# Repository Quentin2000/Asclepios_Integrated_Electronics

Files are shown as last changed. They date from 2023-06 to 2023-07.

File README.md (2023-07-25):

# Master Project

## Integration of a miniaturized O2 sensor into a space suit helmet.

#### Author: Quentin Delfosse
#### Academic Supervisor: Pr. Guillermo Villanueva
#### Technical Supervisor: Arnault Monoyer

## Repository files

This repository includes the following design files:
- **HW**: Kicad hardware files for the interface board and air quality sensor board.
- **SW**: Arduino files used to flash the ESP32 S2 Mini 1 computer.
- **SD**: Setup files for the SD card.

To access CAD design files, please refer to the Google Drive: https://drive.google.com/drive/folders/1vZVMf6BT2zpStATiHxgfttCtssU6DIhK?usp=drive_link.

## Introduction

Asclepios is a student-led project from Switzerland aiming at organizing simulations of manned space missions. For this purpose, the association rents existing infrastructure and builds its base inside. Therefore, by design, the mission will take place on Earth, where many parameters are different than on other celestial bodies. However, the analog astronauts will live together in close contact during the two weeks of the mission to experience the constraints of extraterrestrial environments during the Earth-based simulation. The project aims at optimizing their environment to make their mission as realistic as possible.

<br />

This project aims at integrating a miniaturized O2 sensor into a space suit helmet to monitor the user's breathable atmosphere. Both mechanical and electrical sensor integration will be required. Additionally, the sensor data will need to be processed. Thus, a graphical interface for the visualization of the O2 data in real time will need to be created.

<p align="center">
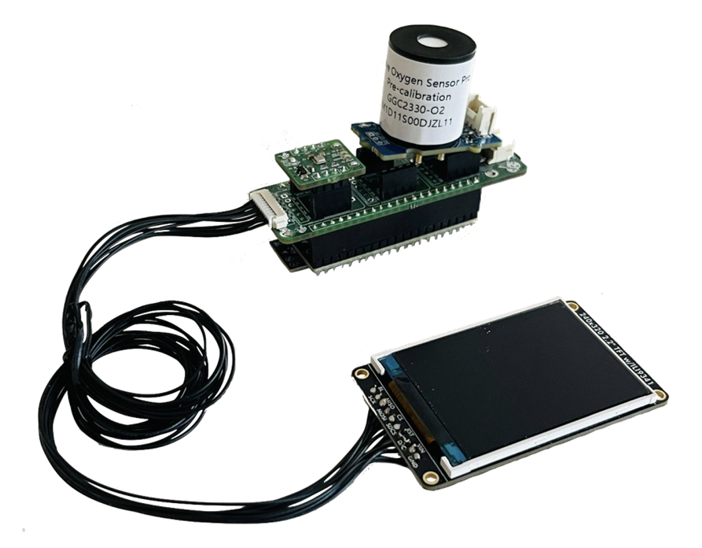
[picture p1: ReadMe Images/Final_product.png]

</p>

## Setup

### Hardware

The system is made of 3 stacked layers:
- **Upper stage**: Sensor stage (O2 + Air quality sensors)
- **Middle stage**: Interface stage 
- **Lower stage**: Main computer stage (ESP32 S2 Mini 1)

**CAREFUL: Before connecting two boards together, please make sure that the signals on both end match! This can be checked on the surface of the boards! Otherwise you may fry the sensors and the computer!**

To assemble the system, simply stack the layers on top of each other:
- Connect the main computer board (black one) to the interface board (long green one).
- **Make sure to check that the signals match: 3V3, Ground, 5V!**
- Insert the SD card into the interface board (bottom face).
- Connect the screen to the interface board (long white connector).
- Connect the Air quality sensor board (small green one) on top of the rooting board (long green one).
- **Again, check that the signals match: 3V3, Ground, 5V!**
- Place the stacked-up module on the 4 rails of the bottom cover. Only one orientation should fit.
- Connect the O2 sensor cable to the O2 sensor board.
- Insert the O2 sensor into the top cover hole, following the 2 rails and making sure that its cable comes out through the dedicated hole on the side.
- Place a foam on top of the interface board where the O2 sensor will be positioned (next to the air quality sensor).
- Close both end on the case together.
- Plug a USB cable to the micro usb port of the main computer and connect it to the portable battery.
- Power up the battery.

The screen should initialize after a couple of seconds and show a similar screen as the following one:
<p align="center">
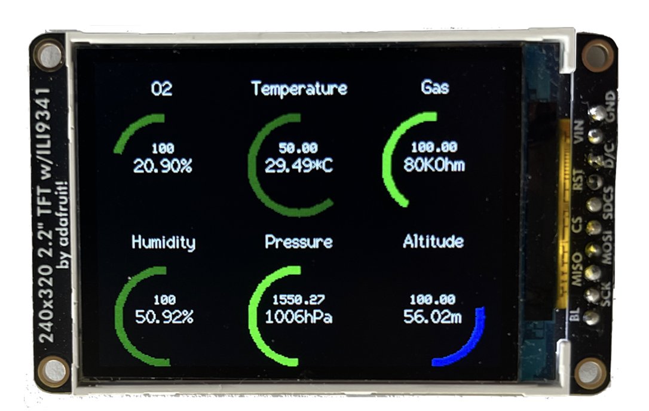
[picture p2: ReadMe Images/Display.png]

</p>

The following figure shows a guidethrough of the procedure.
<p align="center">
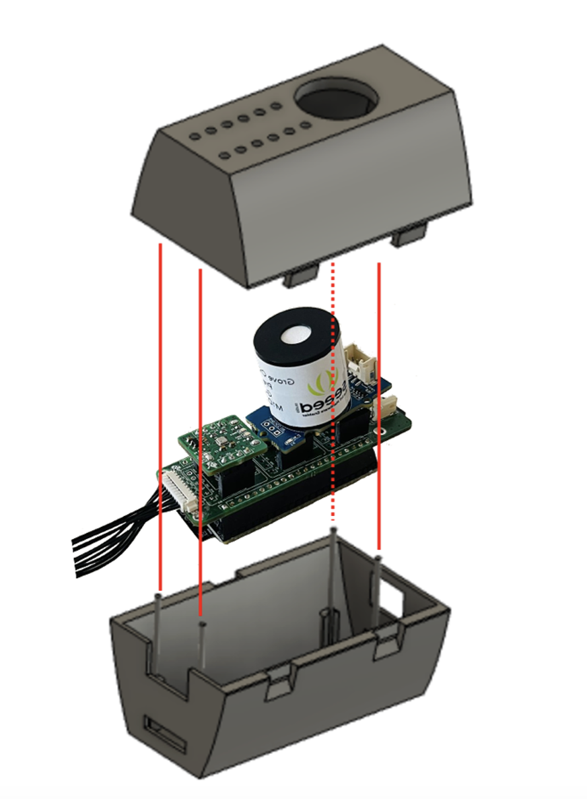
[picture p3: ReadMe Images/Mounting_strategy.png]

</p>

### Software

To display the sensors data, you will need the following package:
```ruby
pip install pandas 
```

To retrieve the data from the SD card, the following procedure must be applied:
- Plug it into your computer
- Open the SD card folder and check the mission log which you want to display
- Open a terminal window
- Go to the SD card directory, something like the following for MAC OS users.
```ruby
 cd /Volumes/NO\ NAME 
```
- Type the following command, where **x** is the number of the mission log to display. You may also need to change to **python** instead of **python3** depending on your computer
```ruby
python3 display.py mission_log_x 
```

This will create a png file with the sensor graphs over the mission duration and an excel file with these values.
<p align="center">
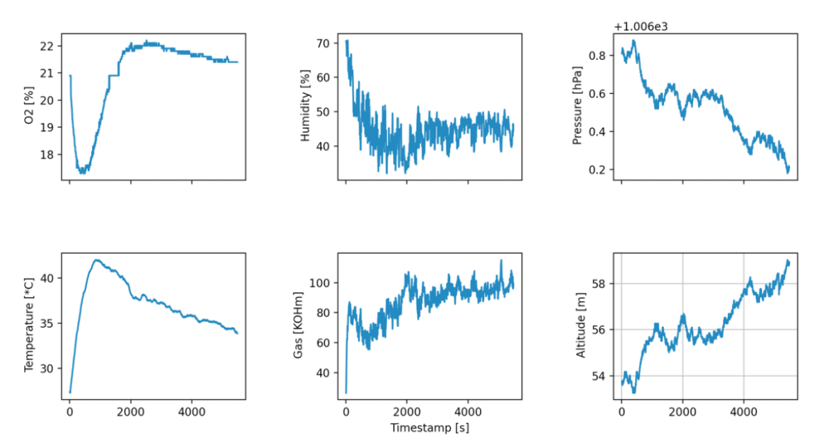
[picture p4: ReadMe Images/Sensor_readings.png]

</p>

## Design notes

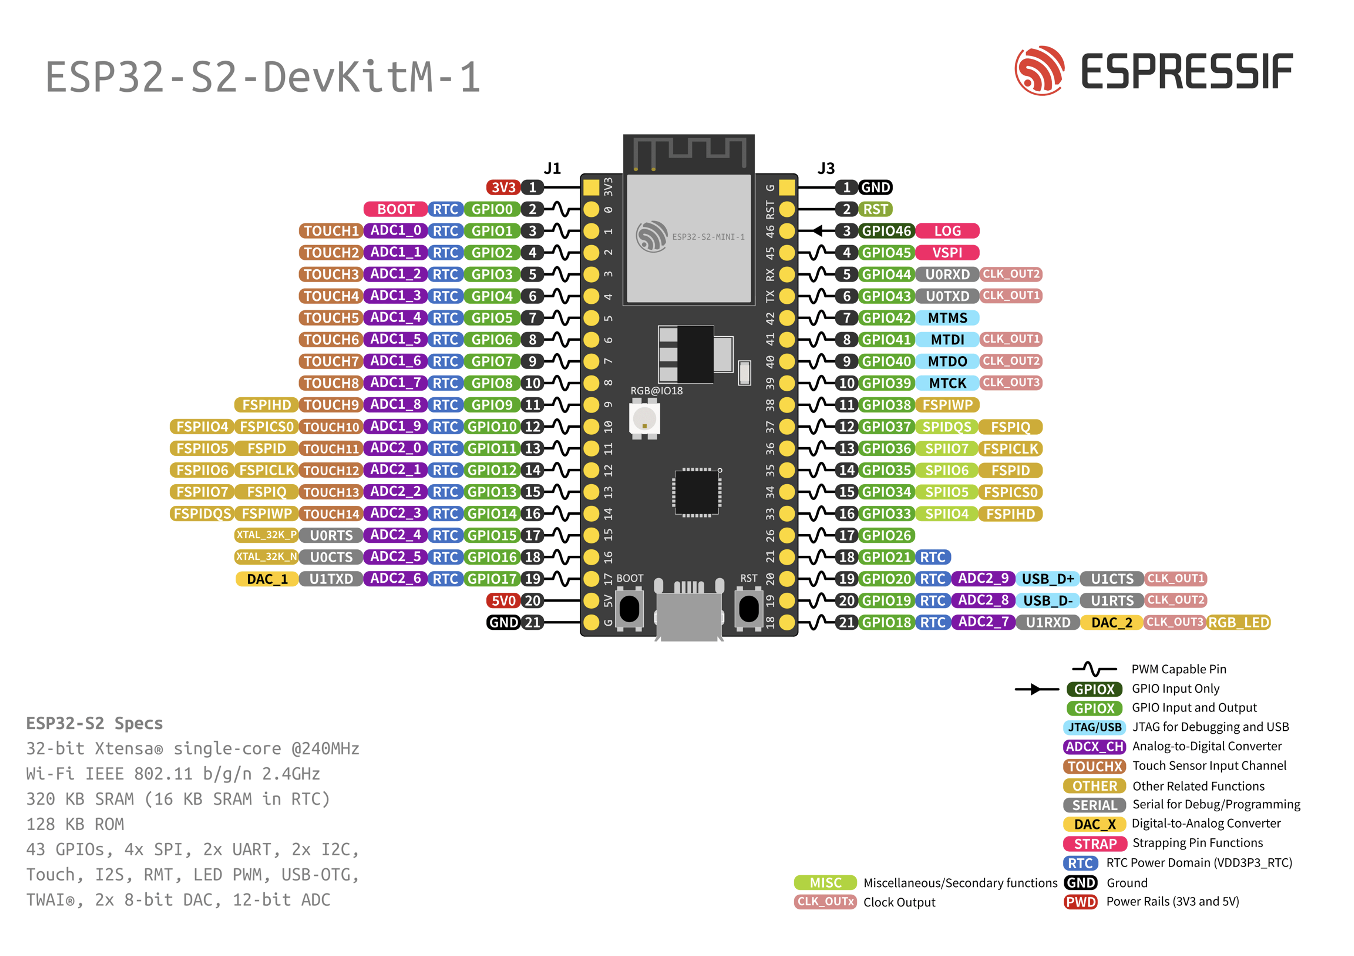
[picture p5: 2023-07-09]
ReadMe Images/Espressif_pinout.png

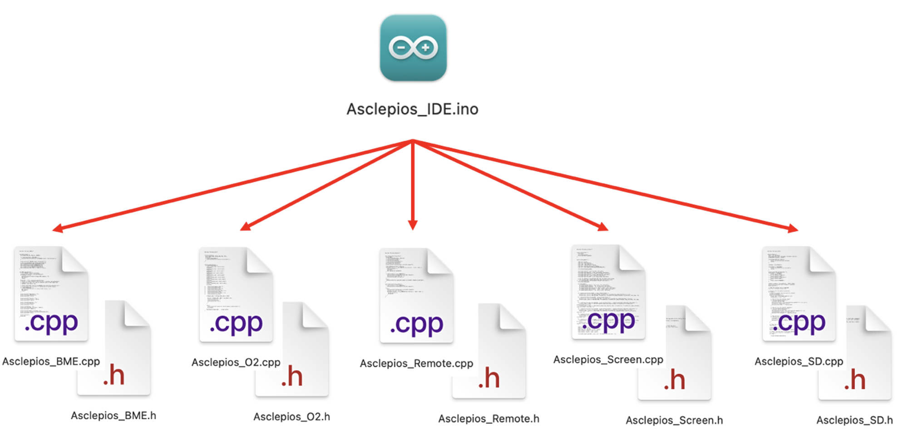
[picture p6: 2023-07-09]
ReadMe Images/SW_Architecture.png

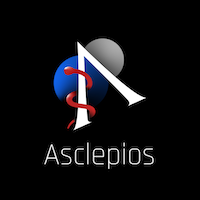
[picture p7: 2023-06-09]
SW/asclepios.bmp

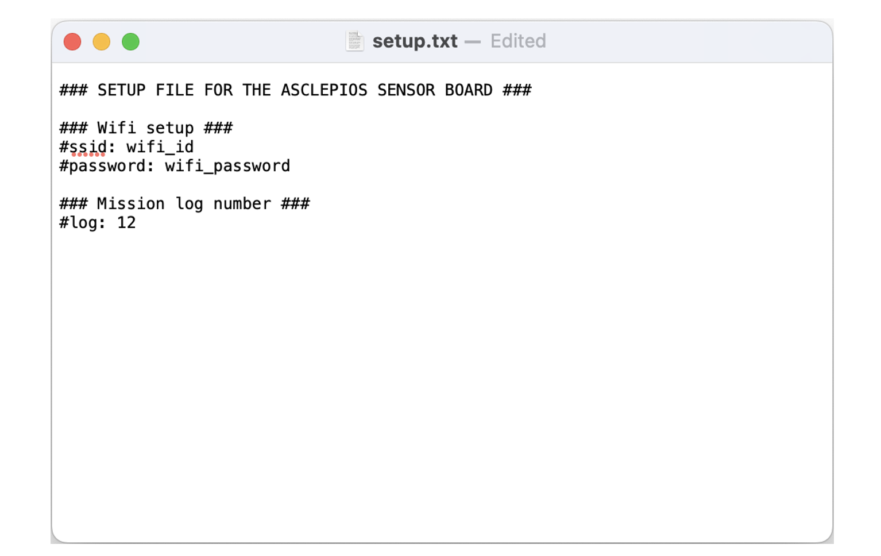
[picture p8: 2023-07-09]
ReadMe Images/SD_config_file.png

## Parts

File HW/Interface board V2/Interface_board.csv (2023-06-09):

Source: | /Users/quentin/Documents/Asclepios/HW/Interface board/Interface_board.kicad_sch
Date: | Wednesday, March 08, 2023 at 01:37:11 PM
Tool: | Eeschema (6.0.8-1)-1
Generator: | /Applications/KiCad/KiCad.app/Contents/SharedSupport/plugins/bom_csv_grouped_by_value.py
Component Count: | 25
Individual Components:
Item | Qty | Reference(s) | Value | LibPart | Footprint | Datasheet | MANUFACTURER | PARTREV | STANDARD
 |  | H0 | MountingHole | Mechanical:MountingHole | MountingHole:MountingHole_2.2mm_M2_DIN965_Pad_TopBottom | ~
 |  | H1 | MountingHole | Mechanical:MountingHole | MountingHole:MountingHole_2.2mm_M2_DIN965_Pad_TopBottom | ~
 |  | H2 | MountingHole | Mechanical:MountingHole | MountingHole:MountingHole_2.2mm_M2_DIN965_Pad_TopBottom | ~
 |  | H3 | MountingHole | Mechanical:MountingHole | MountingHole:MountingHole_2.2mm_M2_DIN965_Pad_TopBottom | ~
 |  | H4 | MountingHole | Mechanical:MountingHole | MountingHole:MountingHole_2.2mm_M2_DIN965_Pad_TopBottom | ~
 |  | J1 | ESP32_Conn_J1 | Connector:Conn_01x21_Female | Connector_PinHeader_2.54mm:PinHeader_1x21_P2.54mm_Vertical | ~
 |  | J2 | Mico_SD_Socket | 503398-1892:503398-1892 | MOLEX_503398-1892 |  | molex | 0 | MANUFACTURER RECOMMENDATIONS
 |  | J3 | ESP32_Conn_J3 | Connector:Conn_01x21_Female | Connector_PinHeader_2.54mm:PinHeader_1x21_P2.54mm_Vertical | ~
 |  | J10 | Conn_01x06_Female | Connector:Conn_01x06_Female | Connector_PinSocket_2.54mm:PinSocket_1x06_P2.54mm_Vertical | ~
 |  | J11 | Conn_01x04_Female | Connector:Conn_01x04_Female | Connector_PinSocket_2.54mm:PinSocket_1x04_P2.54mm_Vertical | ~
 |  | J12 | Conn_01x04_Female | Connector:Conn_01x04_Female | Connector_PinSocket_2.54mm:PinSocket_1x04_P2.54mm_Vertical | ~
 |  | J13 | Conn_01x04_Female | Connector:Conn_01x04_Female | Connector_PinSocket_2.54mm:PinSocket_1x04_P2.54mm_Vertical | ~
 |  | J20 | Conn_01x06_Female | Connector:Conn_01x06_Female | Connector_PinSocket_2.54mm:PinSocket_1x06_P2.54mm_Vertical | ~
 |  | J21 | Conn_01x04_Female | Connector:Conn_01x04_Female | Connector_PinSocket_2.54mm:PinSocket_1x04_P2.54mm_Vertical | ~
 |  | J22 | Conn_01x04_Female | Connector:Conn_01x04_Female | Connector_PinSocket_2.54mm:PinSocket_1x04_P2.54mm_Vertical | ~
 |  | J23 | Conn_01x04_Female | Connector:Conn_01x04_Female | Connector_PinSocket_2.54mm:PinSocket_1x04_P2.54mm_Vertical | ~
 |  | J30 | Conn_01x06_Female | Connector:Conn_01x06_Female | Connector_PinSocket_2.54mm:PinSocket_1x06_P2.54mm_Vertical | ~
 |  | J31 | Conn_01x04_Female | Connector:Conn_01x04_Female | Connector_PinSocket_2.54mm:PinSocket_1x04_P2.54mm_Vertical | ~
 |  | J32 | Conn_01x04_Female | Connector:Conn_01x04_Female | Connector_PinSocket_2.54mm:PinSocket_1x04_P2.54mm_Vertical_SMD_Pin1Left | ~
 |  | J33 | Conn_01x04_Female | Connector:Conn_01x04_Female | Connector_PinSocket_2.54mm:PinSocket_1x04_P2.54mm_Vertical | ~
 |  | J40 | Screen_connector | Connector:Conn_01x10_Female | Connector_Molex:Molex_PicoBlade_53048-1010_1x10_P1.25mm_Horizontal | ~
 |  | JP1 | SolderJumper_3_Open | Jumper:SolderJumper_3_Open | Jumper:SolderJumper-3_P1.3mm_Open_RoundedPad1.0x1.5mm | ~
 |  | JP2 | SolderJumper_3_Open | Jumper:SolderJumper_3_Open | Jumper:SolderJumper-3_P1.3mm_Open_RoundedPad1.0x1.5mm | ~
 |  | JP3 | SolderJumper_3_Open | Jumper:SolderJumper_3_Open | Jumper:SolderJumper-3_P1.3mm_Open_RoundedPad1.0x1.5mm | ~
 |  | JP4 | SolderJumper_3_Open | Jumper:SolderJumper_3_Open | Jumper:SolderJumper-3_P1.3mm_Open_RoundedPad1.0x1.5mm | ~
Collated Components:
Item | Qty | Reference(s) | Value | LibPart | Footprint | Datasheet | MANUFACTURER | PARTREV | STANDARD
1 | 5 | H0, H1, H2, H3, H4 | MountingHole | Mechanical:MountingHole | MountingHole:MountingHole_2.2mm_M2_DIN965_Pad_TopBottom | ~
2 | 1 | J1 | ESP32_Conn_J1 | Connector:Conn_01x21_Female | Connector_PinHeader_2.54mm:PinHeader_1x21_P2.54mm_Vertical | ~
3 | 1 | J2 | Mico_SD_Socket | 503398-1892:503398-1892 | MOLEX_503398-1892 |  | molex | 0 | MANUFACTURER RECOMMENDATIONS
4 | 1 | J3 | ESP32_Conn_J3 | Connector:Conn_01x21_Female | Connector_PinHeader_2.54mm:PinHeader_1x21_P2.54mm_Vertical | ~
5 | 3 | J10, J20, J30 | Conn_01x06_Female | Connector:Conn_01x06_Female | Connector_PinSocket_2.54mm:PinSocket_1x06_P2.54mm_Vertical | ~
6 | 8 | J11, J12, J13, J21, J22, J23, J31, J33 | Conn_01x04_Female | Connector:Conn_01x04_Female | Connector_PinSocket_2.54mm:PinSocket_1x04_P2.54mm_Vertical | ~
7 | 1 | J32 | Conn_01x04_Female | Connector:Conn_01x04_Female | Connector_PinSocket_2.54mm:PinSocket_1x04_P2.54mm_Vertical_SMD_Pin1Left | ~
8 | 1 | J40 | Screen_connector | Connector:Conn_01x10_Female | Connector_Molex:Molex_PicoBlade_53048-1010_1x10_P1.25mm_Horizontal | ~
9 | 4 | JP1, JP2, JP3, JP4 | SolderJumper_3_Open | Jumper:SolderJumper_3_Open | Jumper:SolderJumper-3_P1.3mm_Open_RoundedPad1.0x1.5mm | ~

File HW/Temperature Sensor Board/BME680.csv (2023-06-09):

Source: | /Users/quentin/Documents/Asclepios/HW/Temperature Sensor Board /BME680.kicad_sch
Date: | Wednesday, March 08, 2023 at 02:31:07 PM
Tool: | Eeschema (6.0.8-1)-1
Generator: | /Applications/KiCad/KiCad.app/Contents/SharedSupport/plugins/bom_csv_grouped_by_value.py
Component Count: | 15
Individual Components:
Item | Qty | Reference(s) | Value | LibPart | Footprint | Datasheet | Description | Height | Manufacturer_Name | Manufacturer_Part_Number | Mouser Part Number | Mouser Price/Stock
 |  | C1 | 100nF | Device:C | Capacitor_SMD:C_0603_1608Metric | ~
 |  | C2 | 100nF | Device:C | Capacitor_SMD:C_0603_1608Metric | ~
 |  | IC1 | BME680 | BME680:BME680 | BME680 | https://datasheet.datasheetarchive.com/originals/distributors/DKDS-24/462907.pdf | Air Quality Sensors Environmental Sensor VOC IIR EMC |  | BOSCH | BME680 | 262-BME680 | https://www.mouser.co.uk/ProductDetail/Bosch-Sensortec/BME680?qs=v271MhAjFHjo0yA%2FC4OnDQ%3D%3D
 |  | J1 | Conn_01x04_Female | Connector:Conn_01x04_Female | Connector_PinHeader_2.54mm:PinHeader_1x04_P2.54mm_Vertical | ~
 |  | J2 | Conn_01x04_Female | Connector:Conn_01x04_Female | Connector_PinHeader_2.54mm:PinHeader_1x04_P2.54mm_Vertical | ~
 |  | LED1 | LB_Q39G-L2OO-35-1 | LB_Q39G-L2OO-35-1:LB_Q39G-L2OO-35-1 | LB_Q39G-L2OO-35-1:LEDC1608X40N |  | Standard LEDs - SMD Blue, 470nm 45mcd, 5mA | 0.4 | OSRAM | LB Q39G-L2OO-35-1 | 720-LBQ39GL2N2351 | https://www.mouser.co.uk/ProductDetail/OSRAM-Opto-Semiconductors/LB-Q39G-L2OO-35-1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
 |  | LED2 | LB_Q39G-L2OO-35-1 | LB_Q39G-L2OO-35-1:LB_Q39G-L2OO-35-1 | LB_Q39G-L2OO-35-1:LEDC1608X40N |  | Standard LEDs - SMD Blue, 470nm 45mcd, 5mA | 0.4 | OSRAM | LB Q39G-L2OO-35-1 | 720-LBQ39GL2N2351 | https://www.mouser.co.uk/ProductDetail/OSRAM-Opto-Semiconductors/LB-Q39G-L2OO-35-1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
 |  | R1 | 4.7k | Device:R | Resistor_SMD:R_0603_1608Metric | ~
 |  | R2 | 4.7k | Device:R | Resistor_SMD:R_0603_1608Metric | ~
 |  | R3 | 100 | Device:R | Resistor_SMD:R_0603_1608Metric | ~
 |  | R4 | 100 | Device:R | Resistor_SMD:R_0603_1608Metric | ~
 |  | R5 | 4.7k | Device:R | Resistor_SMD:R_0603_1608Metric | ~
 |  | SJ1 | SOLDERJUMPER | Adafruit BMP390-eagle-import:SOLDERJUMPER | Jumper:SolderJumper-2_P1.3mm_Open_RoundedPad1.0x1.5mm
 |  | SJ2 | SOLDERJUMPER | Adafruit BMP390-eagle-import:SOLDERJUMPER | Jumper:SolderJumper-2_P1.3mm_Open_RoundedPad1.0x1.5mm
 |  | SJ3 | SolderJumper_3_Open | Jumper:SolderJumper_3_Open | Jumper:SolderJumper-3_P1.3mm_Open_RoundedPad1.0x1.5mm | ~
Collated Components:
Item | Qty | Reference(s) | Value | LibPart | Footprint | Datasheet | Description | Height | Manufacturer_Name | Manufacturer_Part_Number | Mouser Part Number | Mouser Price/Stock
1 | 2 | C1, C2 | 100nF | Device:C | Capacitor_SMD:C_0603_1608Metric | ~
2 | 1 | IC1 | BME680 | BME680:BME680 | BME680 | https://datasheet.datasheetarchive.com/originals/distributors/DKDS-24/462907.pdf | Air Quality Sensors Environmental Sensor VOC IIR EMC |  | BOSCH | BME680 | 262-BME680 | https://www.mouser.co.uk/ProductDetail/Bosch-Sensortec/BME680?qs=v271MhAjFHjo0yA%2FC4OnDQ%3D%3D
3 | 2 | J1, J2 | Conn_01x04_Female | Connector:Conn_01x04_Female | Connector_PinHeader_2.54mm:PinHeader_1x04_P2.54mm_Vertical | ~
4 | 2 | LED1, LED2 | LB_Q39G-L2OO-35-1 | LB_Q39G-L2OO-35-1:LB_Q39G-L2OO-35-1 | LB_Q39G-L2OO-35-1:LEDC1608X40N |  | Standard LEDs - SMD Blue, 470nm 45mcd, 5mA | 0.4 | OSRAM | LB Q39G-L2OO-35-1 | 720-LBQ39GL2N2351 | https://www.mouser.co.uk/ProductDetail/OSRAM-Opto-Semiconductors/LB-Q39G-L2OO-35-1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
5 | 3 | R1, R2, R5 | 4.7k | Device:R | Resistor_SMD:R_0603_1608Metric | ~
6 | 2 | R3, R4 | 100 | Device:R | Resistor_SMD:R_0603_1608Metric | ~
7 | 2 | SJ1, SJ2 | SOLDERJUMPER | Adafruit BMP390-eagle-import:SOLDERJUMPER | Jumper:SolderJumper-2_P1.3mm_Open_RoundedPad1.0x1.5mm
8 | 1 | SJ3 | SolderJumper_3_Open | Jumper:SolderJumper_3_Open | Jumper:SolderJumper-3_P1.3mm_Open_RoundedPad1.0x1.5mm | ~

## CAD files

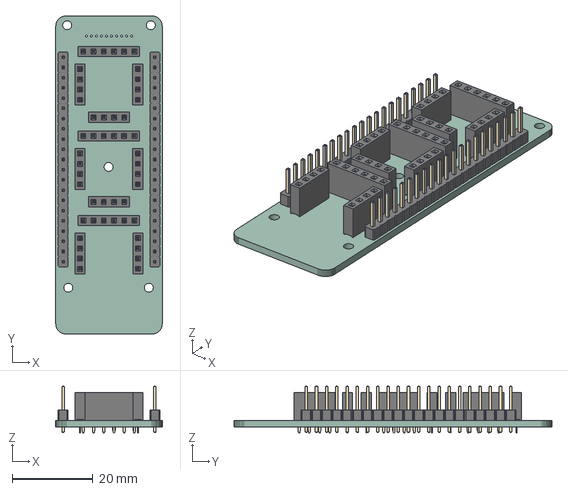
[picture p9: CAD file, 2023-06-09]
HW/Interface board V2/Interface_board.step
26.5 x 79.0 x 11.6 mm
PCB

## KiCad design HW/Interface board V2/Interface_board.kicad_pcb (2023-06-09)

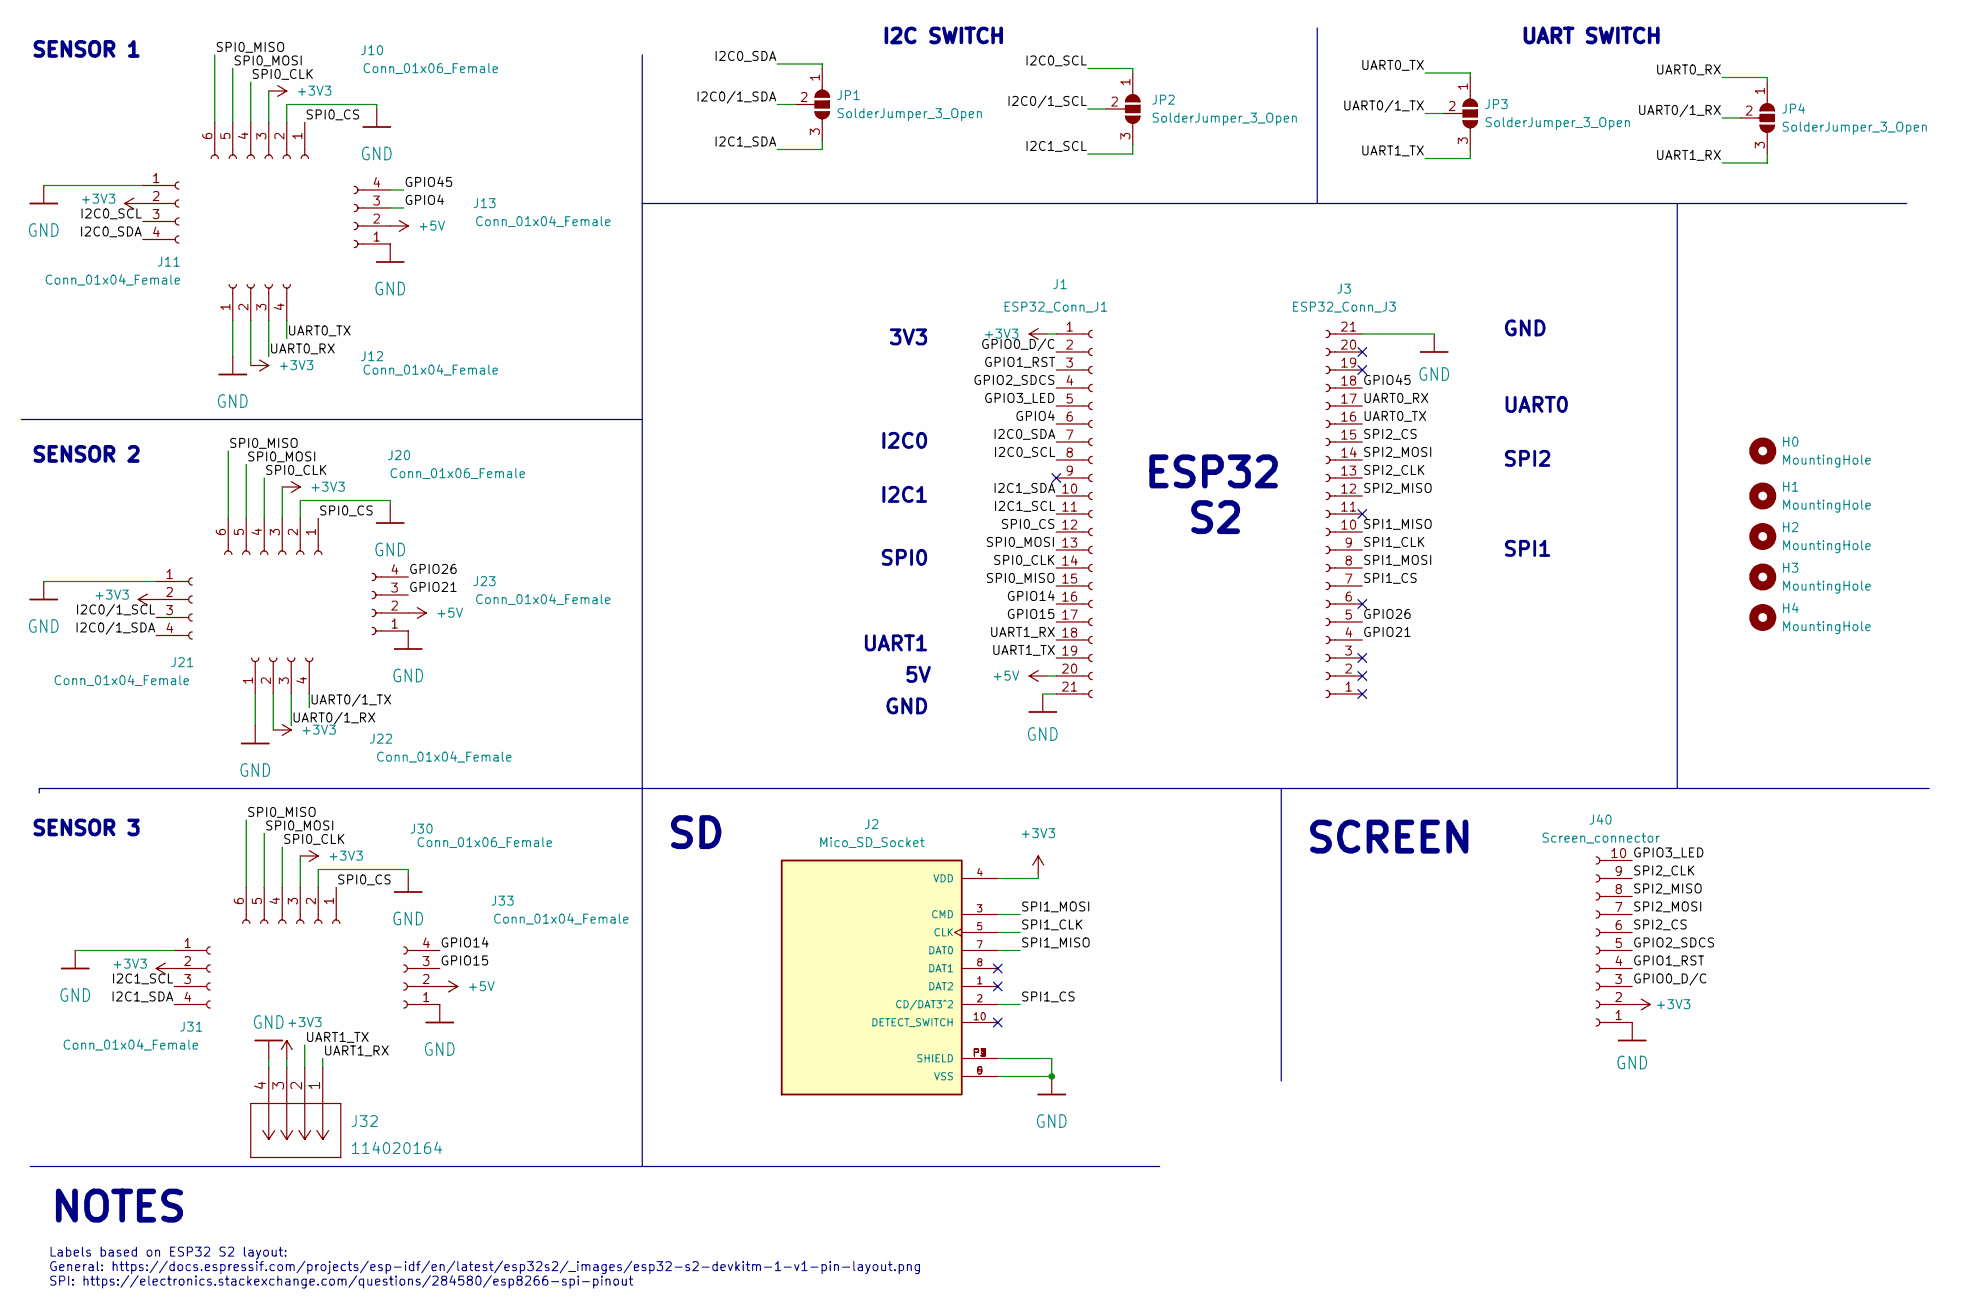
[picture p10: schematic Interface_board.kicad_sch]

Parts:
H0, H1, H2, H3, H4: MountingHole; MountingHole_2.2mm_M2_DIN965_Pad_TopBottom
J1: ESP32_Conn_J1; PinHeader_1x21_P2.54mm_Vertical
J2: Mico_SD_Socket; MOLEX_503398-1892; PARTREV 0
J3: ESP32_Conn_J3; PinHeader_1x21_P2.54mm_Vertical
J10, J20, J30: Conn_01x06_Female; PinSocket_1x06_P2.54mm_Vertical
J11, J12, J13, J21, J22, J23, J31, J33: Conn_01x04_Female; PinSocket_1x04_P2.54mm_Vertical
J32: 114020164; Conn_seed_114020164
J40: Screen_connector; Molex_PicoBlade_53048-1010_1x10_P1.25mm_Horizontal
JP1, JP2, JP3, JP4: SolderJumper_3_Open; SolderJumper-3_P1.3mm_Open_RoundedPad1.0x1.5mm

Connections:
+3V3: J1.1, J2.4 (VDD), J10.3, J11.2, J12.2, J20.3, J21.2, J22.2, J30.3, J31.2, J32.3, J40.2
+5V: J1.20, J13.2, J23.2, J33.2
/GPIO0_D/C: J1.2, J40.3
/GPIO1_RST: J1.3, J40.4
/GPIO2_SDCS: J1.4, J40.5
/GPIO3_LED: J1.5, J40.10
/GPIO4: J1.6, J13.3
/GPIO14: J1.16, J33.4
/GPIO15: J1.17, J33.3
/GPIO21: J3.4, J23.3
/GPIO26: J3.5, J23.4
/GPIO45: J3.18, J13.4
/I2C0_SCL: J1.8, J11.3, JP2.1 (A)
/I2C0_SDA: J1.7, J11.4, JP1.1 (A)
/I2C0/1_SCL: J21.3, JP2.2 (C)
/I2C0/1_SDA: J21.4, JP1.2 (C)
/I2C1_SCL: J1.11, J31.3, JP2.3 (B)
/I2C1_SDA: J1.10, J31.4, JP1.3 (B)
/SPI0_CLK: J1.14, J10.4, J20.4, J30.4
/SPI0_CS: J1.12, J10.1, J20.1, J30.1
/SPI0_MISO: J1.15, J10.6, J20.6, J30.6
/SPI0_MOSI: J1.13, J10.5, J20.5, J30.5
/SPI1_CLK: J2.5 (CLK), J3.9
/SPI1_CS: J2.2 (CD/DAT3^2), J3.7
/SPI1_MISO: J2.7 (DAT0), J3.10
/SPI1_MOSI: J2.3 (CMD), J3.8
/SPI2_CLK: J3.13, J40.9
/SPI2_CS: J3.15, J40.6
/SPI2_MISO: J3.12, J40.8
/SPI2_MOSI: J3.14, J40.7
/UART0_RX: J3.17, J12.3, JP4.1 (A)
/UART0_TX: J3.16, J12.4, JP3.1 (A)
/UART0/1_RX: J22.3, JP4.2 (C)
/UART0/1_TX: J22.4, JP3.2 (C)
/UART1_RX: J1.18, J32.1, JP4.3 (B)
/UART1_TX: J1.19, J32.2, JP3.3 (B)
GND: J1.21, J2.6 (VSS), J2.9 (VSS), J2.P1 (SHIELD), J2.P2 (SHIELD), J2.P3 (SHIELD), J2.P4 (SHIELD), J3.21, J10.2, J11.1, J12.1, J13.1, J20.2, J21.1, J22.1, J23.1, J30.2, J31.1, J32.4, J33.1, J40.1

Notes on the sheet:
SENSOR 3
SCREEN
GND
UART1
Labels based on ESP32 S2 layout: General: https://docs.espressif.com/projects/esp-idf/en/latest/esp32s2/_images/esp32-s2-devkitm-1-v1-pin-layout.png SPI: https://electronics.stackexchange.com/questions/284580/esp8266-spi-pinout
3V3
I2C SWITCH
I2C1
ESP32 S2
I2C0
SPI1
SPI0
SENSOR 1
NOTES
UART0
UART SWITCH
SPI2
SENSOR 2

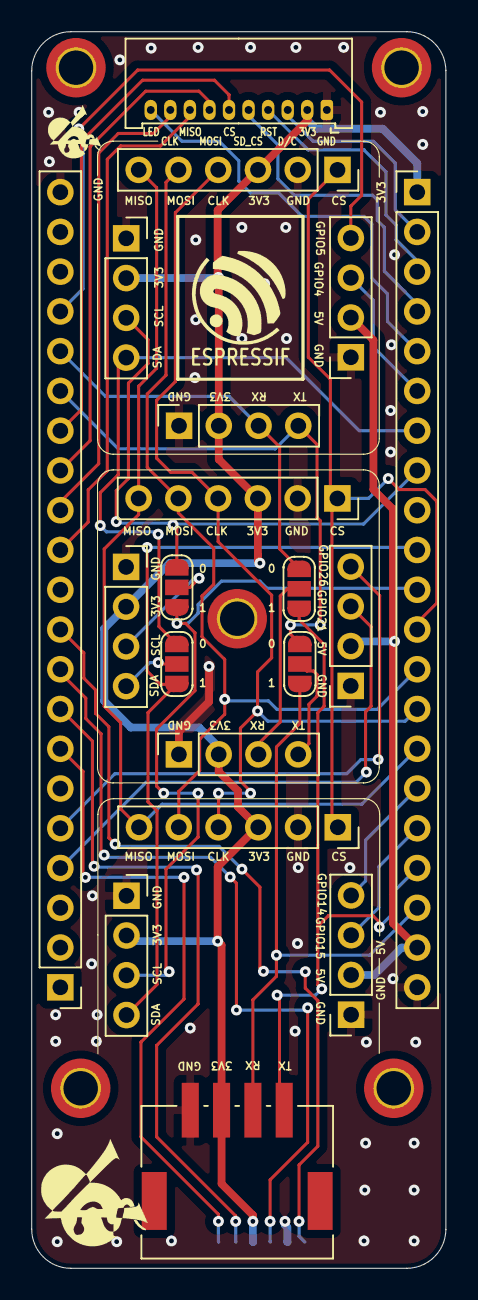
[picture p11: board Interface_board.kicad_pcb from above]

Board: 2 copper layers, 26.5 x 79.0 mm, 25 parts (1 on the bottom side), 37 nets.

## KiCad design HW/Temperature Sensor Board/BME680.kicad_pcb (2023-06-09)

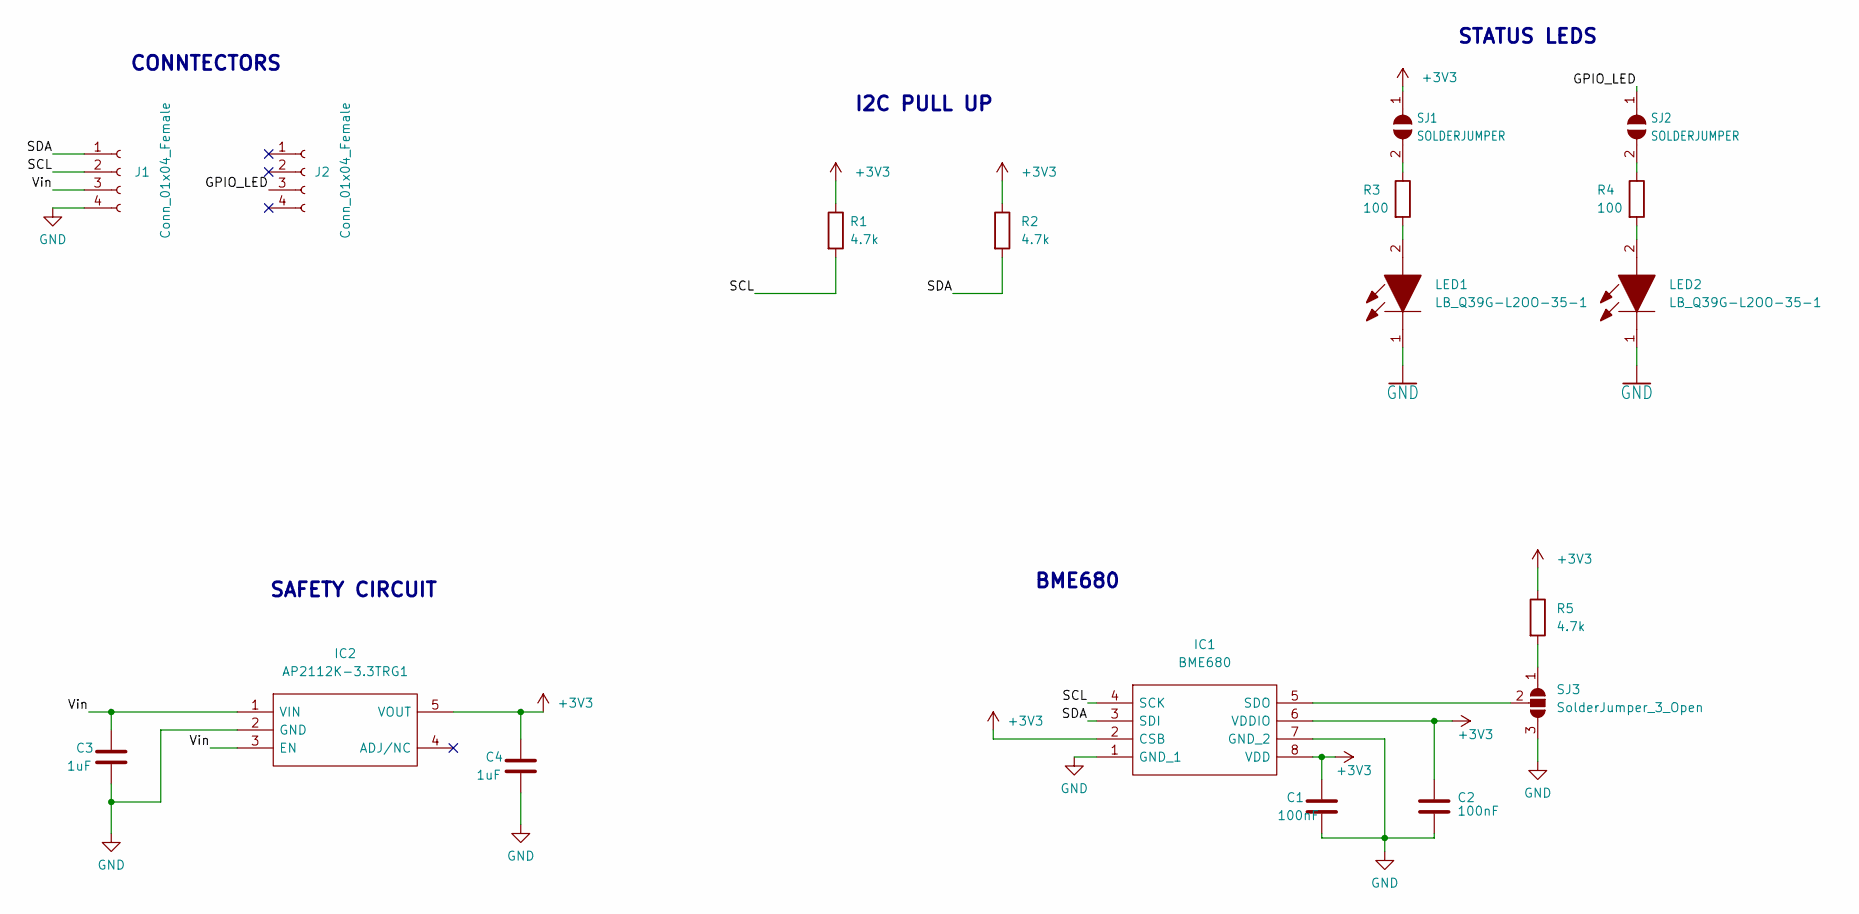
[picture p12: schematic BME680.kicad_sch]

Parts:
C1, C2: 100nF; C_0603_1608Metric
C3, C4: 1uF; C_0603_1608Metric
IC1: BME680; Mouser Part Number 262-BME680
IC2: AP2112K-3.3TRG1; SOT95P282X130-5N; Mouser Part Number 621-AP2112K-3.3TRG1
J1, J2: Conn_01x04_Female; PinHeader_1x04_P2.54mm_Vertical
LED1, LED2: LB_Q39G-L2OO-35-1; LEDC1608X40N; Mouser Part Number 720-LBQ39GL2N2351
R1, R2, R5: 4.7k; R_0603_1608Metric
R3, R4: 100; R_0603_1608Metric
SJ1, SJ2: SOLDERJUMPER; SolderJumper-2_P1.3mm_Open_RoundedPad1.0x1.5mm
SJ3: SolderJumper_3_Open; SolderJumper-3_P1.3mm_Open_RoundedPad1.0x1.5mm

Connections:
+3V3: C1.1, C2.1, C4.1, IC1.2 (CSB), IC1.6 (VDDIO), IC1.8 (VDD), IC2.5 (VOUT), R1.1, R2.1, R5.1, SJ1.1
/GPIO_LED: J2.3, SJ2.1
/SCL: IC1.4 (SCK), J1.2, R1.2
/SDA: IC1.3 (SDI), J1.1, R2.2
/Vin: C3.1, IC2.1 (VIN), IC2.3 (EN), J1.3
GND: C1.2, C2.2, C3.2, C4.2, IC1.1 (GND_1), IC1.7 (GND_2), IC2.2 (GND), J1.4, LED1.1, LED2.1, SJ3.3 (B)
unnamed: IC1.5 (SDO), SJ3.2 (C)
unnamed: LED1.2, R3.2
unnamed: LED2.2, R4.2
unnamed: R3.1, SJ1.2
unnamed: R4.1, SJ2.2
unnamed: R5.2, SJ3.1 (A)

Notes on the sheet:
BME680
STATUS LEDS
I2C PULL UP
CONNTECTORS
SAFETY CIRCUIT

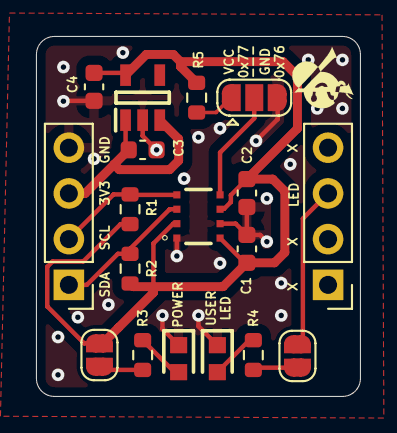
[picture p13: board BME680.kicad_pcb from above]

Board: 2 copper layers, 18.0 x 20.0 mm, 18 parts (0 on the bottom side), 12 nets.

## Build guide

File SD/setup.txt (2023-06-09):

### SETUP FILE FOR THE ASCLEPIOS SENSOR BOARD ###

### Wifi setup ###
#ssid: wifi_id
#password: wifi_password

### Mission log number ###
#log: 12

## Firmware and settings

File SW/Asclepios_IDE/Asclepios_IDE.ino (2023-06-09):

#include "Asclepios_IDE.h"
#include "Asclepios_SD.h"
#include "Asclepios_Remote.h"
#include "Asclepios_O2.h"
#include "Asclepios_BME.h"
#include "Asclepios_Screen.h"

#define __min(a,b) ((a)<(b)?(a):(b)) 
#define __max(a,b) ((a)>(b)?(a):(b))

// WIFI Setup
char ssid [64];
char password [64];
String HOST_NAME = "http://172.20.10.4"; // Local Host's IP address to be changed 
// String PATH_NAME   = "/insert_temp.php";
// String queryString = "?temperature=30.5";

// UART1 (O2 sensor)
HardwareSerial Uart1(1);
float O2_val = 0.0; // [%] default value
float old_o2 = 0;    // [%]
float min_O2 = 19.5; // [%] according to safety regulations
float max_O2 = 23.5; // [%] according to safety regulations

// I2C1 (BME sensor)
Adafruit_BME680 bme; // I2C
float min_pres = 0.47*ATM; // [*C] according to safety regulations
float max_pres = 1.53*ATM; // [*C] according to safety regulations
float old_pres = 0;
float min_temp = -10.0; // [*C] according to safety regulations
float max_temp = 50.0; // [*C] according to safety regulations
float old_temp = 0;
float min_hum = 40.0; // [%] according to safety regulations
float max_hum = 70.0; // [%] according to safety regulations
float old_hum = 0;
float max_alt = 400; // [m] for display purposes
float min_alt = 0; // [m] for display purposes
float old_alt = 0;
float max_gas = 400; // [KOhm] for display purposes
float min_gas = 0; // [KOhm] for display purposes
float old_gas = 0;

// /!\ CAREFUL, DO NOT CHOOSE MAX_VAL = 2*MIN_VAL AS A DIVISION BY 0 ERROR WILL OCCUR SOMEHOW /!\

// SPI1 (SD card)
SPIClass * SPI1 = NULL;
uint8_t cardType = CARD_NONE;
uint16_t mission_log_nbr = 0;
char mission_log_file [64];

// SPI2 (Screen) (defined in the Arduino/libraries/TFT_eSPI/User_Setup.h file)
//#define SPI2_MISO   39
//#define SPI2_MOSI   41
//#define SPI2_SCLK   40
//#define SPI2_SS     42
TFT_eSPI tft = TFT_eSPI();       // Invoke custom library
float Text_font = 2.0;
uint16_t x_o2 = 1*tft.height()/6;
uint16_t y_o2 = 8*tft.width()/24;
uint16_t x_hum = 1*tft.height()/6;
uint16_t y_hum = 20*tft.width()/24;
uint16_t x_temp = 3*tft.height()/6;
uint16_t y_temp = 8*tft.width()/24;
uint16_t x_pres = 3*tft.height()/6;
uint16_t y_pres = 20*tft.width()/24;
uint16_t x_gas = 5*tft.height()/6;
uint16_t y_gas = 8*tft.width()/24;
uint16_t x_alt = 5*tft.height()/6;
uint16_t y_alt = 20*tft.width()/24;
byte base_green = 100; // over 256 values
int brightness = 100; // [%]
int graph_thickness = 5;
float screen_refresh_thresh = 1.0;
int init_loop = 1;


void setup() {
  
  Serial.begin(115200);
  Serial.println();
  Serial.println(F("Welcome to the Asclepios 3.0 Onboard Computer!"));
  Serial.println();

  SD_setup();
  // remote_monitoring_setup();
  screen_setup();
  O2_setup();
  BME_setup();
}

void loop() {
  
  O2_acquisition();
  delay(1000);
  BME_acquisition();
  delay(10);
  screen_update();
  delay(10);
  SD_update();
  delay(10);
  // remote_monitoring_update();
  // delay(10);
}

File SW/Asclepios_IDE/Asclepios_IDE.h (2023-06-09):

#include <Wire.h>
#include <SPI.h>
#include <TFT_eSPI.h>
#include <WiFi.h>
#include <HardwareSerial.h>
#include <Adafruit_Sensor.h>
#include "Adafruit_BME680.h"
#include "FS.h"
#include "SD.h"
#include "SPI.h"

//#include <stdlib.h>

#define __min(a,b) ((a)<(b)?(a):(b)) 
#define __max(a,b) ((a)>(b)?(a):(b))

// WIFI Setup
extern char ssid [64];
extern char password [64];
extern String HOST_NAME; // Local Host's IP address to be changed 
// String PATH_NAME   = "/insert_temp.php";
// String queryString = "?temperature=30.5";

// UART1 (O2 sensor)
#define RX1 16
#define TX1 17
extern HardwareSerial Uart1;
extern float O2_val; // [%] default value
extern float old_o2;    // [%]
extern float min_O2; // [%] according to safety regulations
extern float max_O2; // [%] according to safety regulations

// I2C1 (BME sensor)
#define BME_SDA 5
#define BME_SCL 6
#define BME_ADDR 0x76
#define SEALEVELPRESSURE_HPA (1013.25)
extern Adafruit_BME680 bme; // I2C
#define ATM 1013.25 // 1 atm = 1013,25 hPa
extern float min_pres; // [*C] according to safety regulations
extern float max_pres; // [*C] according to safety regulations
extern float old_pres;
extern float min_temp; // [*C] according to safety regulations
extern float max_temp; // [*C] according to safety regulations
extern float old_temp;
extern float min_hum; // [%] according to safety regulations
extern float max_hum; // [%] according to safety regulations
extern float old_hum;
extern float max_alt; // [m] for display purposes
extern float min_alt; // [m] for display purposes
extern float old_alt;
extern float max_gas; // [KOhm] for display purposes
extern float min_gas; // [KOhm] for display purposes
extern float old_gas;

// /!\ CAREFUL, DO NOT CHOOSE MAX_VAL = 2*MIN_VAL AS A DIVISION BY 0 ERROR WILL OCCUR SOMEHOW /!\

// SPI1 (SD card)
#define SPI1_MISO   MISO  // 37
#define SPI1_MOSI   MOSI  // 35
#define SPI1_SCLK   SCK   // 36
#define SPI1_SS     SS    // 34
extern SPIClass * SPI1;
extern uint8_t cardType;
extern uint16_t mission_log_nbr;
extern char mission_log_file [64];

// SPI2 (Screen) (defined in the Arduino/libraries/TFT_eSPI/User_Setup.h file)
//#define SPI2_MISO   39
//#define SPI2_MOSI   41
//#define SPI2_SCLK   40
//#define SPI2_SS     42
extern TFT_eSPI tft;       // Invoke custom library
extern float Text_font;
extern uint16_t x_o2;
extern uint16_t y_o2;
extern uint16_t x_hum;
extern uint16_t y_hum;
extern uint16_t x_temp;
extern uint16_t y_temp;
extern uint16_t x_pres;
extern uint16_t y_pres;
extern uint16_t x_gas;
extern uint16_t y_gas;
extern uint16_t x_alt;
extern uint16_t y_alt;
#define DEG2RAD 0.0174532925
extern byte base_green; // over 256 values
extern int brightness; // [%]
extern int graph_thickness;
extern float screen_refresh_thresh;
extern int init_loop;

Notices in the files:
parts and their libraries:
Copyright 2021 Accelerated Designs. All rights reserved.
